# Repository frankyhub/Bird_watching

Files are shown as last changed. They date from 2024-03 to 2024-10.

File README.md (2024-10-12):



<div align="center">

|[:skull:ISSUE](https://github.com/frankyhub/Bird_watching/issues?q=is%3Aissue)|[:speech_balloon: Forum /Discussion](https://github.com/frankyhub/Bird_watching/discussions)|[:grey_question:WiKi](https://github.com/frankyhub/Bird_watching/wiki)||
|--|--|--|--|
| | | | |
||<a href="https://github.com/frankyhub/Bird_watching/issues">|<a href="https://github.com/frankyhub/Bird_watching/discussions">|<a href="https://github.com/frankyhub/Bird_watching/releases">|
|| <a href="https://github.com/frankyhub/Bird_watching/pulse" alt="Activity">| <a href="https://github.com/frankyhub/Bird_watching/graphs/traffic">  |<a href="https://github.com/frankyhub?tab=stars"> |
</div>

# Bird watching 
### Nach einer Idee von [Alex Kutschera](https://github.com/vektorious)

### Story
Die Blaumeise und die Kohlmeise gehören zu den häufigsten Meisenarten in Deutschland. Sie gehen nicht nur gerne an Futterhäuschen, sondern suchen auch Nistkästen auf, in denen sie Schutz suchen und ihre Familie gründen können. Für jede Vogelart gibt es eine ideale Größe des Einfluglochs. Bei den kleinen Blaumeisen sind das 28 Millimeter Durchmesser, bei den größeren Kohlmeisen 32 und beim Star 45mm Lochgröße. Die Lightburnvorlage ist für Kohlmeisen ausgelegt.  Das Einflugloch sollte in Richtung Ost / Südost ausgerichtet sein. 

Die Kohlmeise ist ein kleiner Singvogel. Sie hat einen schwarzen Kopf, weiße Wangen und gelbes Gefieder an Brust und Bauch, sie sind etwa 11 bis 12 Zentimeter groß und wiegen zwischen 9 und 12 Gramm. Mit der CAM des ESP32 und dem WEB-Server kann man in den Nistkasten das Schlüpfen der Jungvögel beobachten. Die 4 IR-LEDs lassen sich über den WEB-Server ein/aus schalten. Der WEB-Server hat eine feste IP-Adresse: 192.160.0.177. Um den WiFi-Empfang des ESP zu verbessern, wurde die Antenne des ESP32-CAM mit 40cm Litze verlängert. In der Testphase ist mit dem Serielllen Monitor die WiFi-Verbindung und die Schaltvorgänge der IR-LEDs zu kontrollieren. Für die Spannungsversorgung ist ein 5V-Netzteil vorgesehen. Möglich ist auch eine Spannungsversorgung mit einem 18650 Akku, der von einem Solor-Panel gespeist wird.

---

### Der WEB-Server:

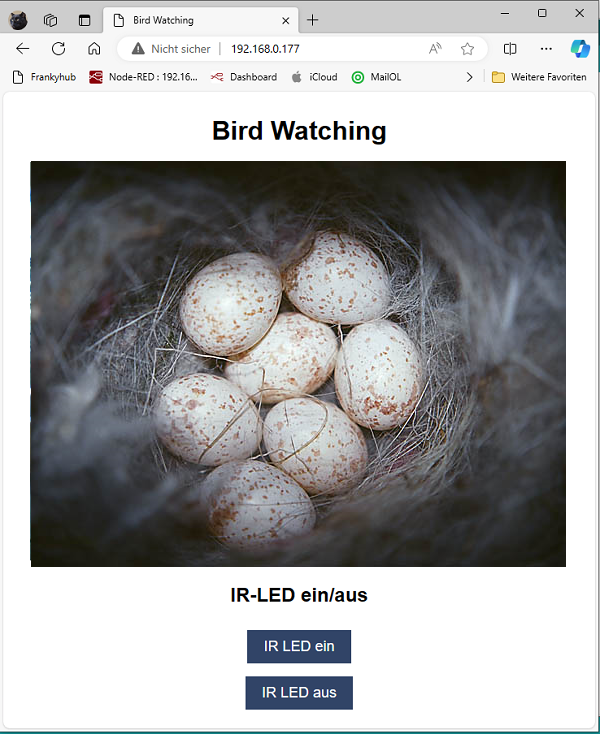
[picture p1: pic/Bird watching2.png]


---

### Serieller Monitor:

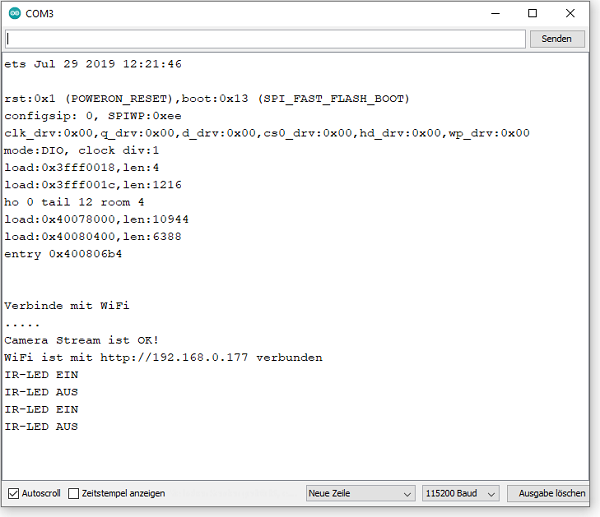
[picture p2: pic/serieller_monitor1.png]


---

### BOM

| Stück | Bezeichnung |
| ----- | --- |
| 1 | ESP32 CAM | 
| 1 | ESP32 CAM Shield | 
| 4 | IR-LEDs 850 nm DC 1,5V 20mA | 
| 4 | 75R 1/4W  | 
| 1 | 10cm Blankdraht  | 
| 1 | 40cm Litze für die Wurfantenne  | 
| 1 | Schaltdraht |
| 1 | 5V Netzteil |
| 1 | Vogelhaus: |
| 2 | Sperrholz 4mm 300x600 |
| ----- | ----------- | 

---

[Bauanleitung](https://github.com/frankyhub/Bird_watching/wiki)

---

### Birdhouse aus dem Lasercutter:

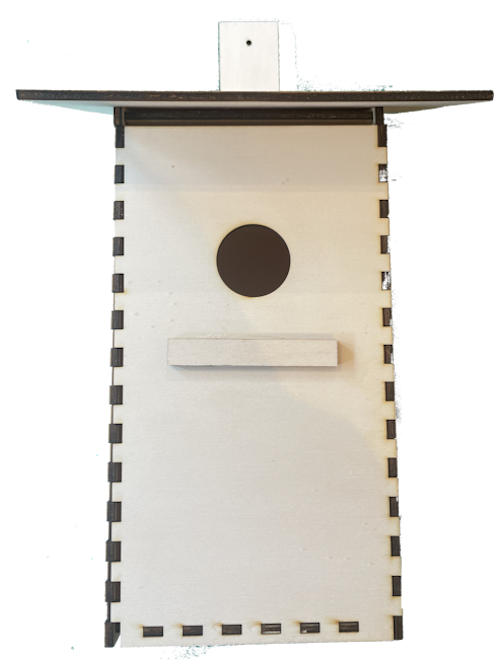
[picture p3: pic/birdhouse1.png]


### CAM-Bild

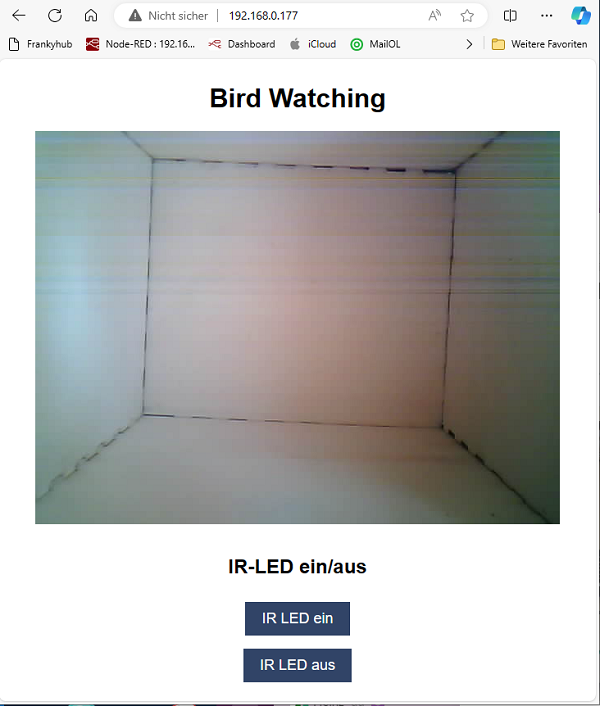
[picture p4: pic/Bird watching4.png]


### Verdrahtung des ESP32-CAM und der IR-LEDs

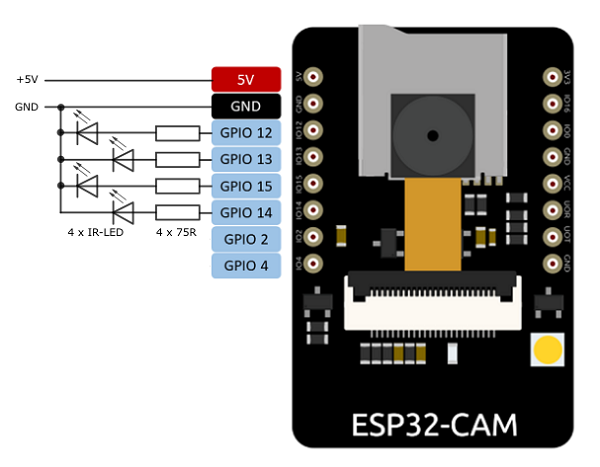
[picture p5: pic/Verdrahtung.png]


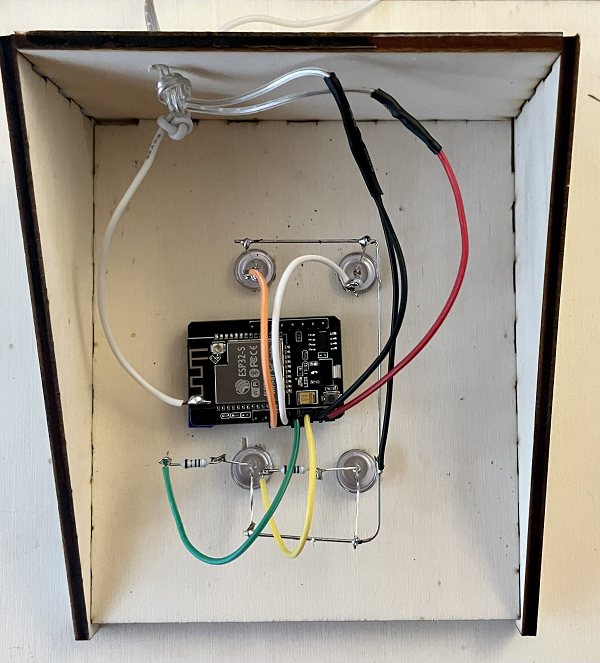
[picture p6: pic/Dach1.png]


---

<div style="position:absolute; left:2cm; ">   
<ol class="breadcrumb" style="border-top: 2px solid black;border-bottom:2px solid black; height: 45px; width: 900px;"> <p align="center"><a href="#oben">nach oben</a></p></ol>
</div>

---

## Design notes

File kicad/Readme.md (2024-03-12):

## ESP32-CAM Shield

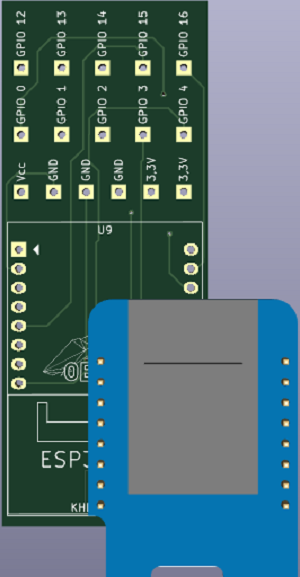
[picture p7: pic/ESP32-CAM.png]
Bild


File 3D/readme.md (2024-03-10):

## ESP32-CAM Spacer

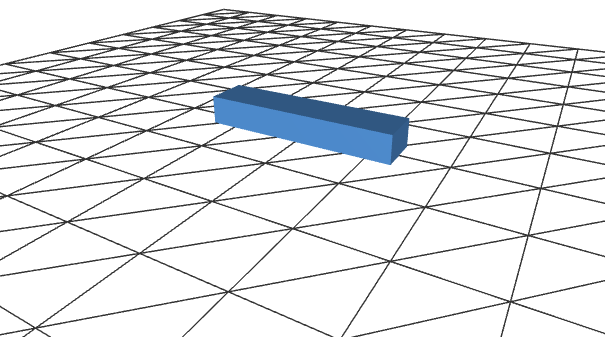
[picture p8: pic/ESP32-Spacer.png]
STL


## Box 1
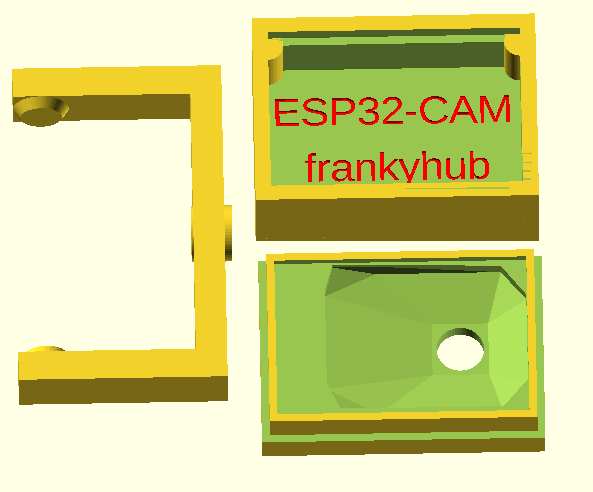
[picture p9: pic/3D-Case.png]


## Box 2
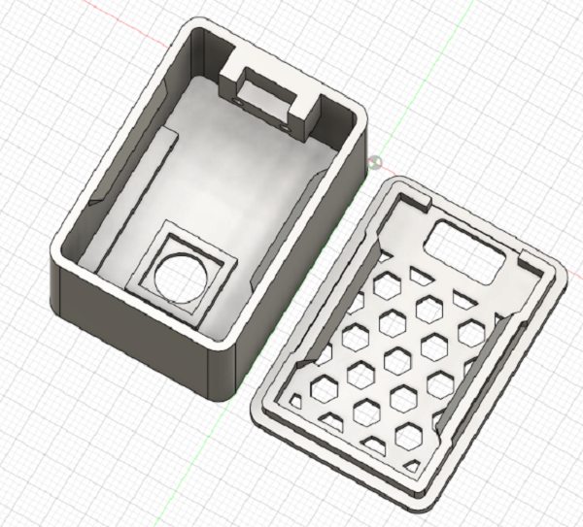
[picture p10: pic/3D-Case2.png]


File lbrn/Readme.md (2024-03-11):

## Lightburn Dach

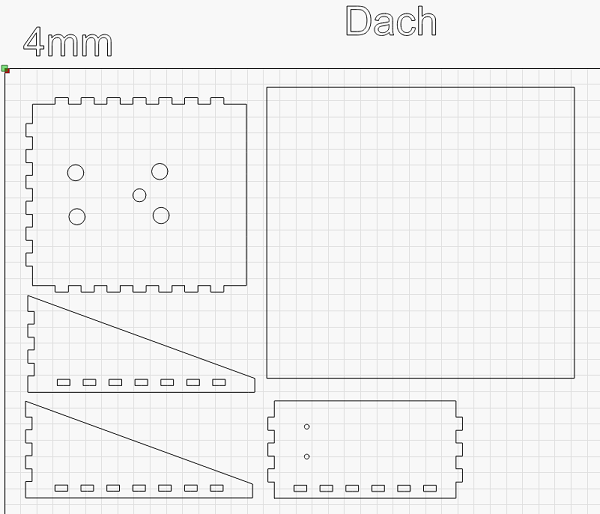
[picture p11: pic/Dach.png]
Bild


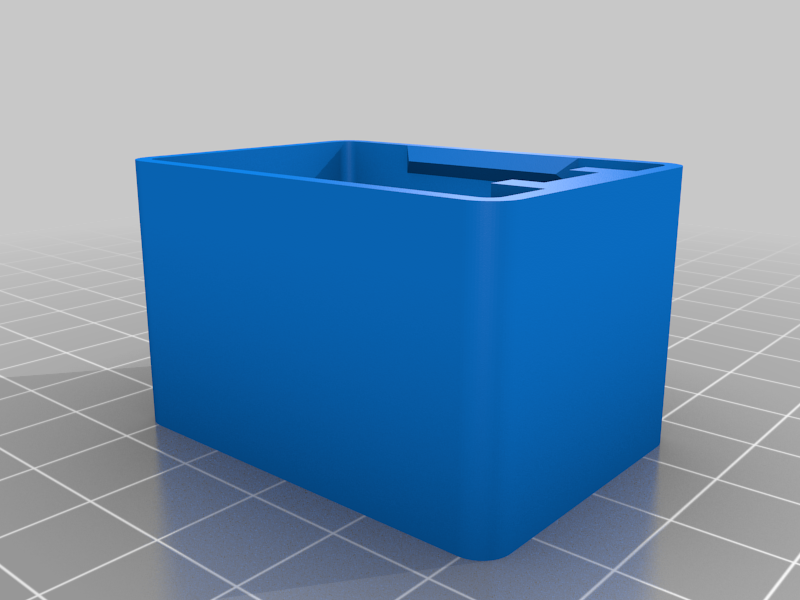
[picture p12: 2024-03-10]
pic/ESP32-CAM-Box2.png

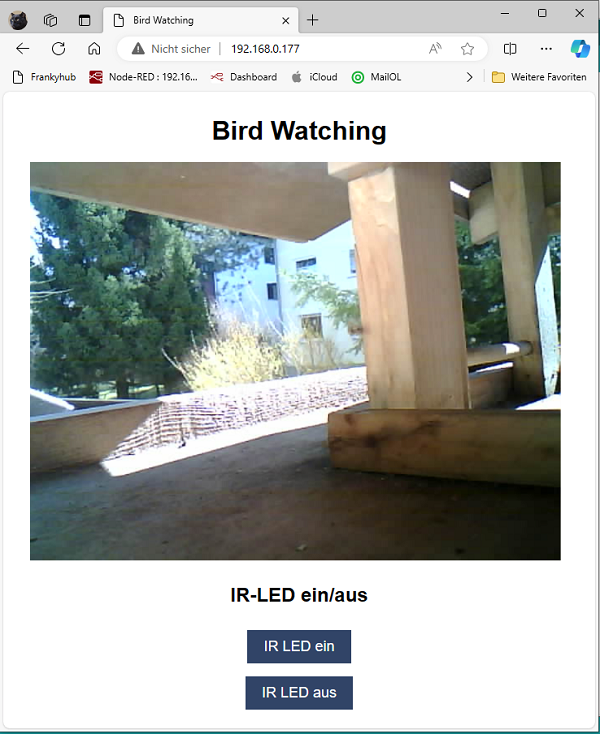
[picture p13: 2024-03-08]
pic/Bird watching1.png

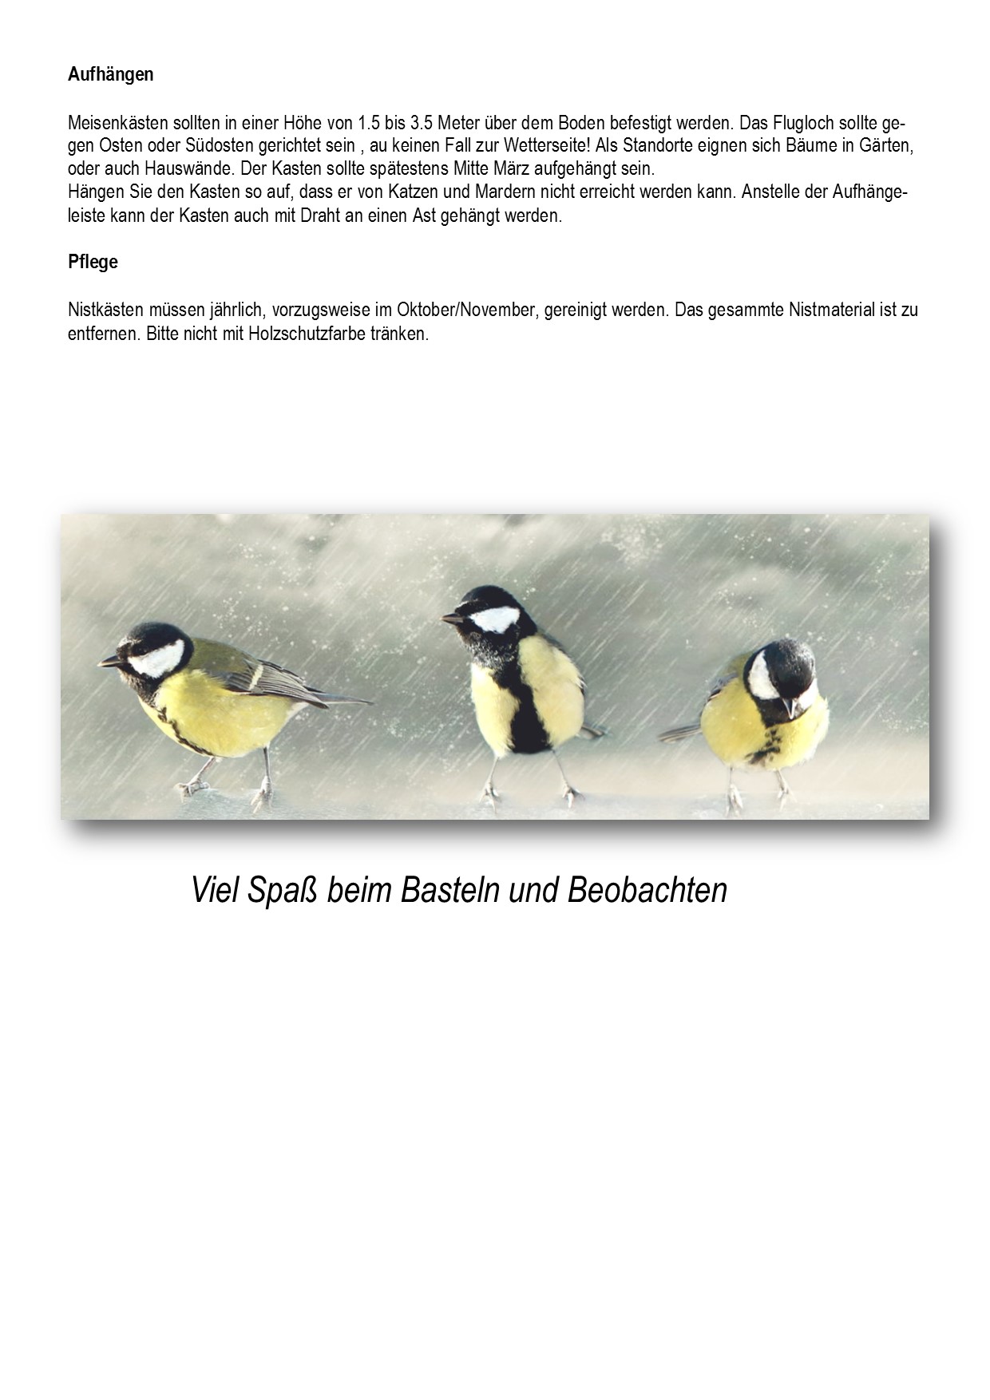
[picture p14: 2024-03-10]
pic/meisenkasten 3.jpg

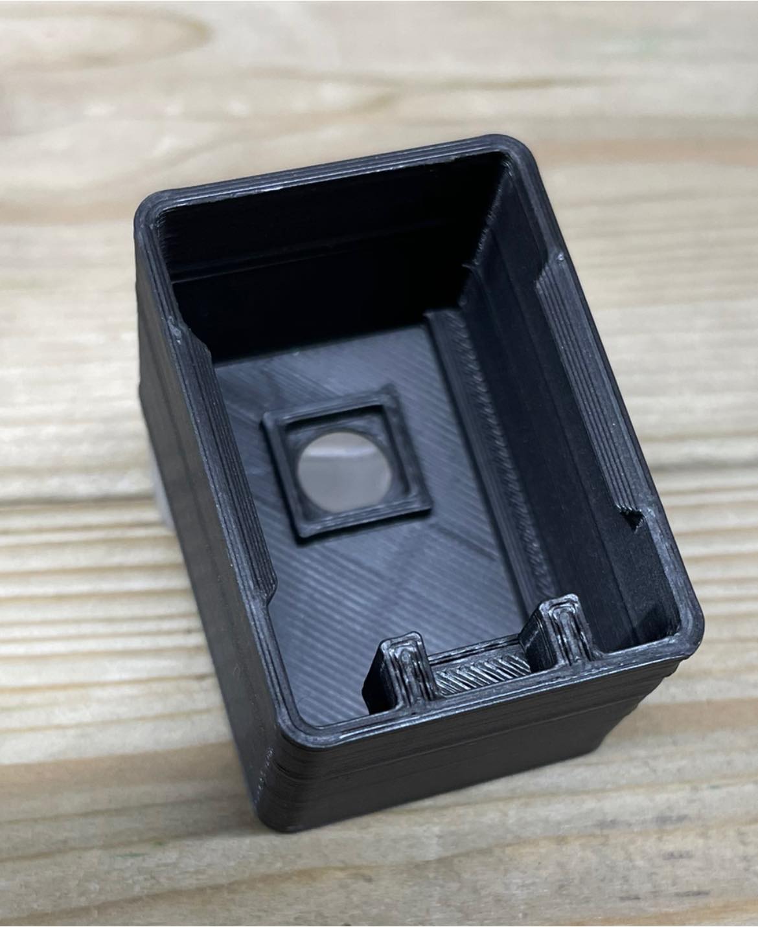
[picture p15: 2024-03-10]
pic/Rear_box2.jpg

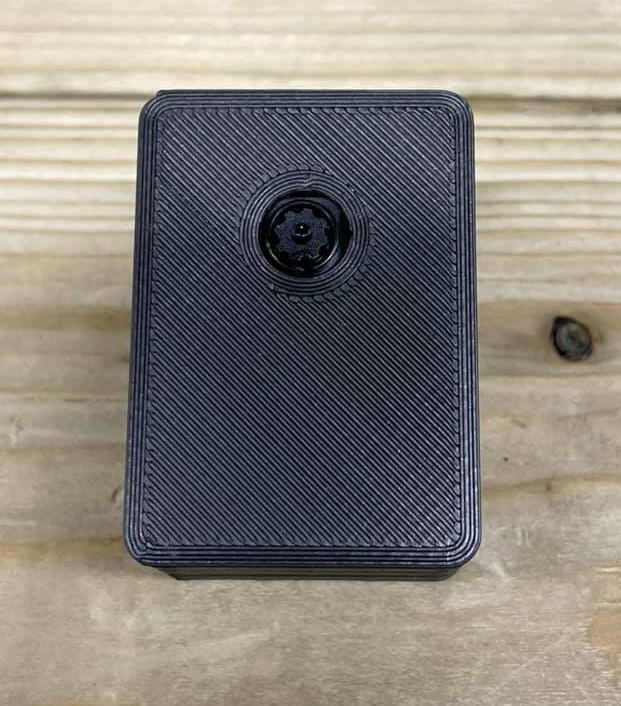
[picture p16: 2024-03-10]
pic/Front_box2.jpg

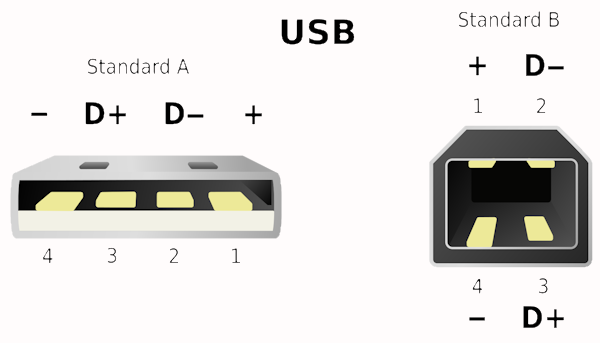
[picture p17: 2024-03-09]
pic/usb.png

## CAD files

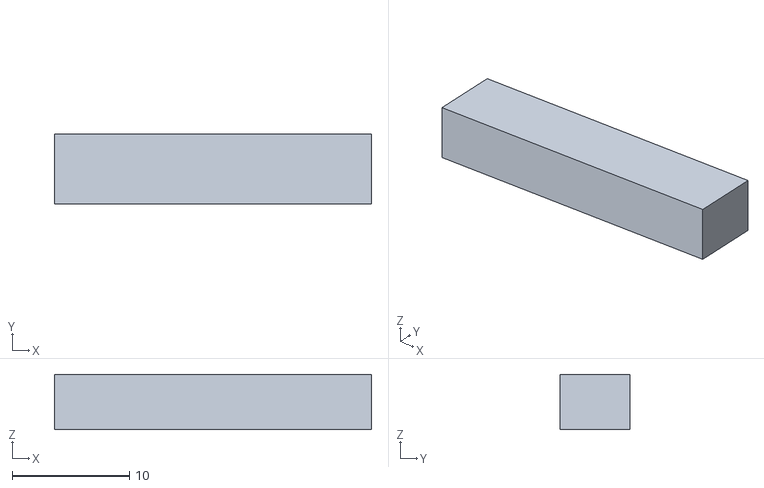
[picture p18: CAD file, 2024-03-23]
3D/ESP Spacer.stl
27.0 x 6.00 x 4.70

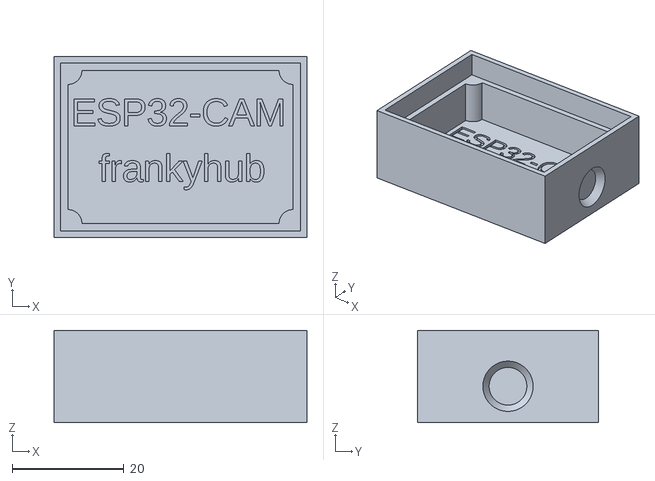
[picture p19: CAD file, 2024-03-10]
3D/esp32cam-box-bottom.stl
45.3 x 32.4 x 16.5

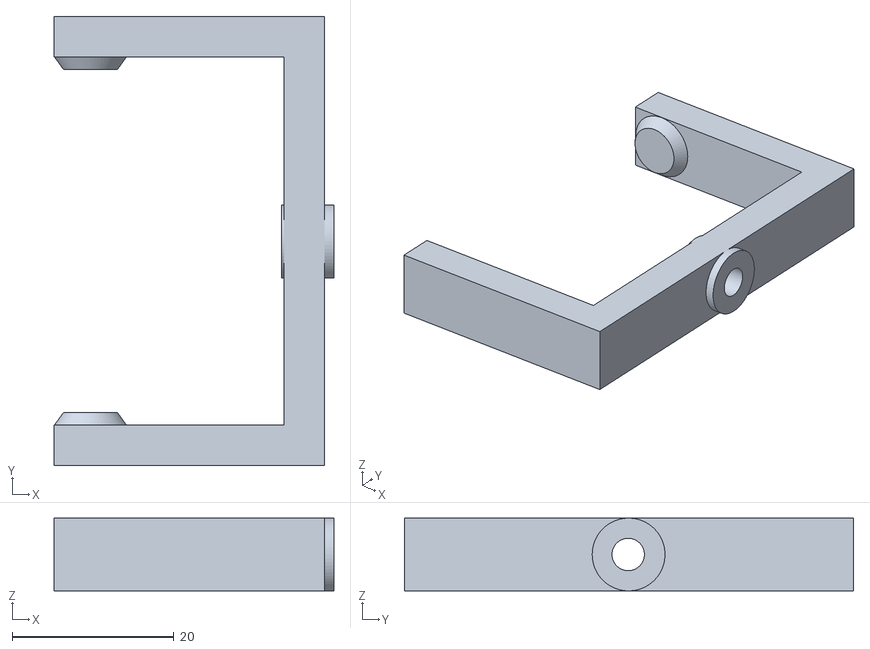
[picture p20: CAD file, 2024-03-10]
3D/esp32cam-box-bracket.stl
34.6 x 55.5 x 9.00

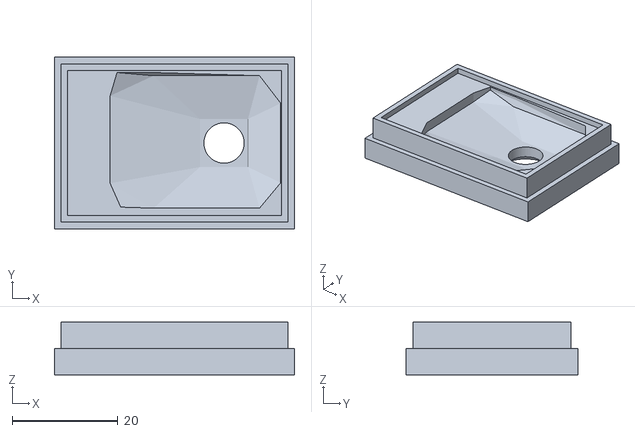
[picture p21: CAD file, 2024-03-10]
3D/esp32cam-box-top.stl
45.3 x 32.4 x 10.0

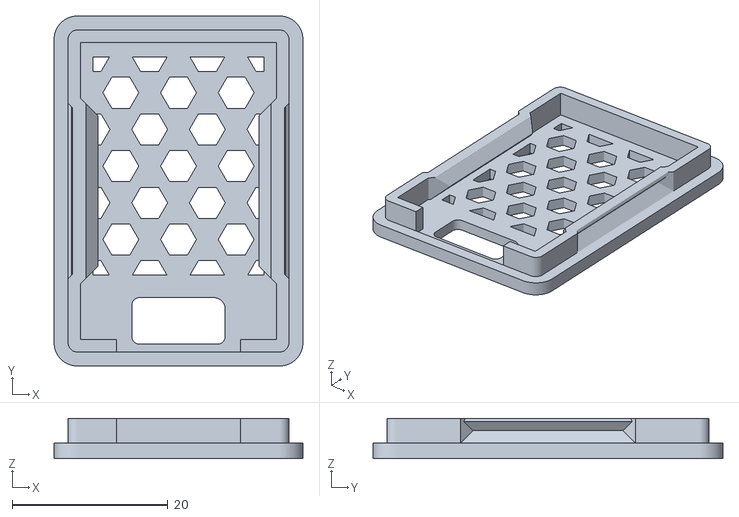
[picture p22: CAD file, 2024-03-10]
3D/ESP32-CAM-Lid2.stl
32.0 x 45.0 x 5.20

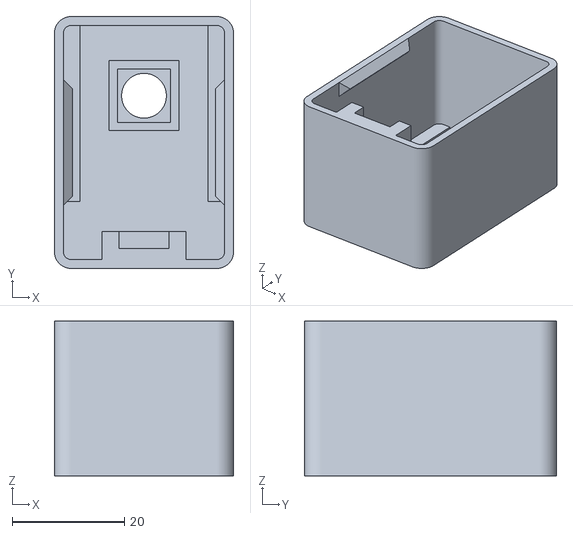
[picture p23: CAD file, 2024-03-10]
3D/ESP32-CAM-Box2.stl
32.0 x 45.0 x 27.6

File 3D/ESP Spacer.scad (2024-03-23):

//ESP Spacer

$fn=60;

cube(size = [27,6,4.7], center = true);

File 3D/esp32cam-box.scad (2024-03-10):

/*
*******************************************
Objekt Info: ESP32-CAM mit Modul-Auswahl

*******************************************
Version: 10.03.2024 khf
*******************************************
*/

//***************   Auswahl   *************

//Auswahl 0=alles, 1= bottom, 2=top, 3=bracket 
        auswahl="0";

//***************   Libraries  ************

//keine

//*****************************************

//***************  Parameter   *************
$fn=60;
//*****************************************

//**************   Programm  **************


pcbx = 40.1+0.2;  // pcb long dimension
pcby = 27.2+0.2;  // pcb shorter dimension
pcbz = 1.05+0.2;  // pcb thickness

lensd = 7.1+0.5;  // lens dia
lensx = 29.5;
lensy = pcby /2.0;
lensz = 5.4;  // bottom of pcb to base of lens
lensh = 2.25+0.2; // height of lens + extra
cambx = 8.65+0.4; // clearance needed for body of camera
camby = 8.65+0.4;

boxwall = 5.0;    // wall thickness
toph   = 10.0;    // thickness of top box

pinh = 9.0;   // how much space needed for pins on rear of pcb

// generate a shape model of the camera upper surface and pcb
// this gets subtracted from a solid base to form a pocket that
// holds the pcb and camera in place.

module camera()
{
  hull()
  {
    translate([lensx-cambx/2,lensy-camby/2,0]) cube([cambx,camby,lensz]);   // camera body
    translate([16.2,1,0]) cube([20,2,3.5]);                                 // room for pins
    translate([16.2,24.0,0]) cube([20,2,3.5]);                              // room for pins
    translate([25.2,pcby/2-7.5,0]) cube([15.0,15.0,3.0]);                   // sdcard slot
    translate([9.3,0.4,0]) cube([7,3.5,2.0]);                               // led + xsistor
    translate([8,4.8,0]) cube([9.4,16.5,3.5]);                              // cam connector
    translate([17.3,3.5,0]) cube([7.75,19.75,3.1]);                         // cable + parts
    translate([10.0,22.3,0]) cube([6.5,3.5,2.2]);                           // reg + parts
  }
  cube([pcbx,pcby,pcbz]);
  //translate([1,pcby-4,pcbz]) rotate([0,0,-90]) linear_extrude(0.5) text("ESP32-CAM",2.5);
  translate([lensx,lensy,lensz]) cylinder(h=lensh, d=lensd);  // lens
  translate([lensx,lensy,lensz+lensh]) cylinder(h=6, d1=lensd, d2=3*lensd); // lens flare
  // below is optional... only needed if you need to put an sd card in the camera
  //translate([40.0,pcby/2-7.5,pcbz]) cube([15.0,15.0,3.0-pcbz]);             // sdcard slot access
}

module boxjoint()
{
  difference()
  {
    cube([pcbx+boxwall,pcby+boxwall,toph/2]);    
    translate([boxwall/4,boxwall/4,0]) cube([pcbx+boxwall/2,pcby+boxwall/2,toph]);
  }
}
module bracket()
{
  hole=4.0;   // mounting hole size
  clrn = 0.1; // clearance for pivot
  difference() 
  {
    union()
    {
      cube([pcbx+boxwall+clrn*2,boxwall,pinh]);
      translate([-boxwall,0,0]) cube([boxwall,pcby+6,pinh]);
      translate([pcbx+boxwall+clrn*2,0,0]) cube([boxwall,pcby+6,pinh]);
      // 2 pins to engage box
      translate([0,pcby-pinh/2+6,pinh/2]) rotate([0,90,0])             cylinder(h=boxwall/3-clrn,d1=pinh-clrn,d2=pinh*0.75-clrn);
      translate([pcbx+boxwall+clrn*2,pcby-pinh/2+6,pinh/2]) rotate([0,-90,0]) cylinder(h=boxwall/3-clrn,d1=pinh-clrn,d2=pinh*0.75-clrn);
      // a reinforcing boss on mounting screw
      translate([(pcbx+boxwall+clrn)/2,-1.2,pinh/2]) rotate([-90,0,0])cylinder(d=pinh,h=boxwall*1.3);

    }
    // cutout mounting hole for #6 screw
    translate([(pcbx+boxwall)/2,-boxwall*5,pinh/2]) rotate([-90,0,0])cylinder(d=hole,h=boxwall*10);
  } 
}

module top()
{
  difference()
  {
    cube([pcbx+boxwall,pcby+boxwall,toph]);
    union()
    {
      translate([boxwall/2,boxwall/2,0]) camera();  // carve out camera
      boxjoint();                                   // carve off the box overlap
    }
  }
}

module bottom()
{
  both = pinh + boxwall/2 + toph/2; // total ht of bottom box
  clr = 0.1;    // a little fudge to make boxes mate
  difference()
  {
    cube([pcbx+boxwall,pcby+boxwall,both]);
    union()
    {
      // cutout for pcb connections
      translate([boxwall/2,boxwall/2,boxwall/2]) cube([pcbx,pcby,both]);
      // cutout for overlap
      translate([boxwall/4-clr/2,boxwall/4-clr/2,both-toph/2]) cube([pcbx+boxwall/2+clr,pcby+boxwall/2+clr,toph/2]);
      //tapered plug cutouts for mounting bracket
      translate([0,(pcby+boxwall)/2,pinh/2+2]) rotate([0,90,0])             cylinder(h=boxwall/3,d1=pinh,d2=pinh*0.75);
      translate([pcbx+boxwall,(pcby+boxwall)/2,pinh/2+2]) rotate([0,-90,0]) cylinder(h=boxwall/3,d1=pinh,d2=pinh*0.75);
      // sign work by embossing inside of bottom of box (adds compute time, but saves some filament!
        
 color( "red", 1.0 ) {        
      translate([3,20,boxwall/2-0.5]) rotate([0,0,0]) linear_extrude(0.55) text("ESP32-CAM",5);
      translate([8,10,boxwall/2-0.5]) rotate([0,0,0]) linear_extrude(0.55) text("frankyhub",5);
      }    
    }
  }
  // add some posts in the corners to hold pcb in top of case when mated
  translate([boxwall/2,boxwall/2,boxwall/2]) cylinder(h=pinh,d=boxwall);
  translate([boxwall/2,boxwall/2+pcby,boxwall/2]) cylinder(h=pinh,d=boxwall);
  translate([boxwall/2+pcbx,boxwall/2,boxwall/2]) cylinder(h=pinh,d=boxwall);
  translate([boxwall/2+pcbx,boxwall/2+pcby,boxwall/2]) cylinder(h=pinh,d=boxwall);
}

module alles(){
    bottom();
    translate([0,-5,toph]) rotate([180,0,0])  top();
    translate([-boxwall,-(pcbx+boxwall)/2,0]) rotate([0,0,90]) bracket();
}


//-----------------------------------------------------------------

module print(){
	if (auswahl == "1") {
		bottom();
	} else if (auswahl == "2") {
		translate([0,-5,toph]) rotate([180,0,0])  
        top();
	} else if (auswahl == "3") {
		// flip top over and move it for printing
        translate([-boxwall,-(pcbx+boxwall)/2,0]) rotate([0,0,90]) 
        bracket();
	} else {
		alles();
	}
}

print();
//-----------------------------------------------------------------

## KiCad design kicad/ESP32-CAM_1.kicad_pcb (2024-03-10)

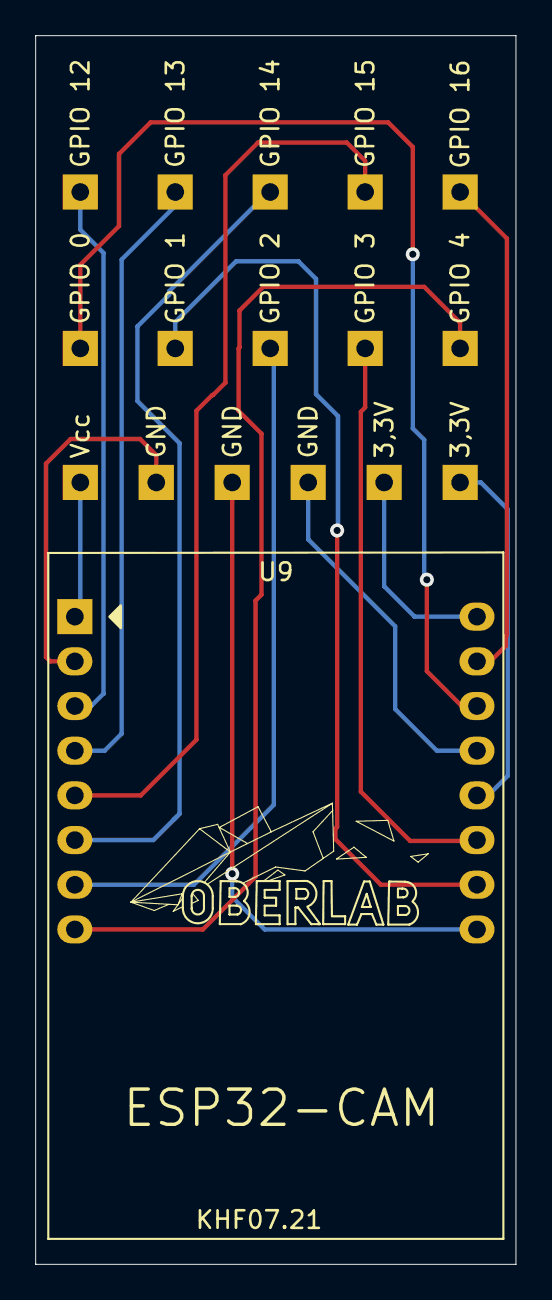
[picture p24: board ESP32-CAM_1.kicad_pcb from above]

Board: 2 copper layers, 27.3 x 69.8 mm, 17 parts (0 on the bottom side), 16 nets.

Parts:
3,3V, 3,3V#2: LP
GND: LP
GND#2, GND#3: LP
GPIO 0, GPIO 1, GPIO 2, GPIO 3, GPIO 4, GPIO 12, GPIO 13, GPIO 14, GPIO 15, GPIO 16: LP
U9: ESP32-CAM
Vcc: LP

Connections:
unnamed: U9.1, Vcc.1
unnamed: GND.1, U9.2
unnamed: GPIO 12.1, U9.3
unnamed: GPIO 13.1, U9.4
unnamed: GPIO 15.1, U9.5
unnamed: GPIO 14.1, U9.6
unnamed: GPIO 2.1, U9.7
unnamed: GPIO 4.1, U9.8
unnamed: 3,3V.1, U9.16
unnamed: GPIO 16.1, U9.15
unnamed: GPIO 0.1, U9.14
unnamed: GND#2.1, U9.13
unnamed: 3,3V#2.1, U9.12
unnamed: GPIO 3.1, U9.11
unnamed: GPIO 1.1, U9.10
unnamed: GND#3.1, U9.9

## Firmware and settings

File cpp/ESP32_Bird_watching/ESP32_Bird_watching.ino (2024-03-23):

/*************************************************************************************************
                                      PROGRAMMINFO
**************************************************************************************************
  Funktion: ESP32-CAM Bird Watching, WEB-Server

  IR-LED on/off
  static IP (192, 168, 0, 177)
**************************************************************************************************
  Version: 07.03.2024
**************************************************************************************************
  Board:  ESP32 Wrover Module
**************************************************************************************************
  C++ Arduino IDE V1.8.13
**************************************************************************************************
  Einstellungen:
  https://dl.espressif.com/dl/package_esp32_index.json
  http://dan.drown.org/stm32duino/package_STM32duino_index.json
  https://raw.githubusercontent.com/espressif/arduino-esp32/gh-pages/package_esp32_dev_index.json
**************************************************************************************************
  Librarys
  - WiFi.h V0.16.1
**************************************************************************************************


**************************************************************************************************/

#include "esp_camera.h"
#include <WiFi.h>
#include "esp_timer.h"
#include "img_converters.h"
#include "Arduino.h"
#include "fb_gfx.h"
#include "esp_http_server.h"


// ***** Trage hier deine WLAN Daten ein *********************************
const char* ssid = "ESP32";
const char* password = "xxx";
//************************************************************************

// ***** Statische IP-Adresse ********************************************
IPAddress local_IP(192, 168, 0, 177);
// Gateway IP Addresse
IPAddress gateway(192, 168, 0, 1);

IPAddress subnet(255, 255, 0, 0);
IPAddress primaryDNS(8, 8, 8, 8);   //optional
IPAddress secondaryDNS(8, 8, 4, 4); //optional

//************************************************************************


#define PART_BOUNDARY "123456789000000000000987654321"

//CAMERA_MODEL_AI_THINKER
#define PWDN_GPIO_NUM     32
#define RESET_GPIO_NUM    -1
#define XCLK_GPIO_NUM      0
#define SIOD_GPIO_NUM     26
#define SIOC_GPIO_NUM     27
#define Y9_GPIO_NUM       35
#define Y8_GPIO_NUM       34
#define Y7_GPIO_NUM       39
#define Y6_GPIO_NUM       36
#define Y5_GPIO_NUM       21
#define Y4_GPIO_NUM       19
#define Y3_GPIO_NUM       18
#define Y2_GPIO_NUM        5
#define VSYNC_GPIO_NUM    25
#define HREF_GPIO_NUM     23
#define PCLK_GPIO_NUM     22


//******* IR-LED *********************************************************
int LED_1 = 12;
int LED_2 = 13;
int LED_3 = 14;
int LED_4 = 15;
//************************************************************************

static const char* _STREAM_CONTENT_TYPE = "multipart/x-mixed-replace;boundary=" PART_BOUNDARY;
static const char* _STREAM_BOUNDARY = "\r\n--" PART_BOUNDARY "\r\n";
static const char* _STREAM_PART = "Content-Type: image/jpeg\r\nContent-Length: %u\r\n\r\n";

//********************WEB-Server ****************************************************
httpd_handle_t camera_httpd = NULL;
httpd_handle_t stream_httpd = NULL;

static const char PROGMEM INDEX_HTML[] = R"rawliteral(
<html>
  <head>
    <title>Bird Watching</title>
    <meta name="viewport" content="width=device-width, initial-scale=1">
    <style>
      body { font-family: Arial; text-align: center; margin:0px auto; padding-top: 30px;}
      table { margin-left: auto; margin-right: auto; }
      td { padding: 8 px; }
      .button {
        background-color: #2f4468;
        border: none;
        color: white;
        padding: 10px 20px;
        text-align: center;
        text-decoration: none;
        display: inline-block;
        font-size: 18px;
        margin: 6px 3px;
        cursor: pointer;
        -webkit-touch-callout: none;
        -webkit-user-select: none;
        -khtml-user-select: none;
        -moz-user-select: none;
        -ms-user-select: none;
        user-select: none;
        -webkit-tap-highlight-color: rgba(0,0,0,0);
      }
      img {  width: auto ;
        max-width: 100% ;
        height: auto ; 
      }
    </style>
  </head>
  <body>
    <h1>Bird Watching</h1>
    <img src="" id="photo" >
    <br>
    <br>
    <h2> IR-LED ein/aus      </h2>

    <table>
      <tr><td colspan="3" align="center"><button class="button" onmousedown="toggleCheckbox('LED_ein');" ontouchstart="toggleCheckbox('LED_ein');">IR LED ein</button></td></tr>
      <tr><td             align="center"><button class="button" onmousedown="toggleCheckbox('LED_aus');" ontouchstart="toggleCheckbox('LED_aus');">IR LED aus</button></td></tr> 
     
   <script>
   function toggleCheckbox(x) {
     var xhr = new XMLHttpRequest();
     xhr.open("GET", "/action?go=" + x, true);
     xhr.send();
   }
   window.onload = document.getElementById("photo").src = window.location.href.slice(0, -1) + ":81/stream";
  </script>
  </body>
</html>
)rawliteral";

//************************************************************************

static esp_err_t index_handler(httpd_req_t *req){
  httpd_resp_set_type(req, "text/html");
  return httpd_resp_send(req, (const char *)INDEX_HTML, strlen(INDEX_HTML));
}

static esp_err_t stream_handler(httpd_req_t *req){
  camera_fb_t * fb = NULL;
  esp_err_t res = ESP_OK;
  size_t _jpg_buf_len = 0;
  uint8_t * _jpg_buf = NULL;
  char * part_buf[64];

  res = httpd_resp_set_type(req, _STREAM_CONTENT_TYPE);
  if(res != ESP_OK){
    return res;
  }

  while(true){
    fb = esp_camera_fb_get();
    if (!fb) {
      Serial.println("Camera capture failed");
      res = ESP_FAIL;
    } else {
      if(fb->width > 400){
        if(fb->format != PIXFORMAT_JPEG){
          bool jpeg_converted = frame2jpg(fb, 80, &_jpg_buf, &_jpg_buf_len);
          esp_camera_fb_return(fb);
          fb = NULL;
          if(!jpeg_converted){
            Serial.println("JPEG compression failed");
            res = ESP_FAIL;
          }
        } else {
          _jpg_buf_len = fb->len;
          _jpg_buf = fb->buf;
        }
      }
    }
    if(res == ESP_OK){
      size_t hlen = snprintf((char *)part_buf, 64, _STREAM_PART, _jpg_buf_len);
      res = httpd_resp_send_chunk(req, (const char *)part_buf, hlen);
    }
    if(res == ESP_OK){
      res = httpd_resp_send_chunk(req, (const char *)_jpg_buf, _jpg_buf_len);
    }
    if(res == ESP_OK){
      res = httpd_resp_send_chunk(req, _STREAM_BOUNDARY, strlen(_STREAM_BOUNDARY));
    }
    if(fb){
      esp_camera_fb_return(fb);
      fb = NULL;
      _jpg_buf = NULL;
    } else if(_jpg_buf){
      free(_jpg_buf);
      _jpg_buf = NULL;
    }
    if(res != ESP_OK){
      break;
    }
   }
  return res;
}

static esp_err_t cmd_handler(httpd_req_t *req){
  char*  buf;
  size_t buf_len;
  char variable[32] = {0,};
  
  buf_len = httpd_req_get_url_query_len(req) + 1;
  if (buf_len > 1) {
    buf = (char*)malloc(buf_len);
    if(!buf){
      httpd_resp_send_500(req);
      return ESP_FAIL;
    }
    if (httpd_req_get_url_query_str(req, buf, buf_len) == ESP_OK) {
      if (httpd_query_key_value(buf, "go", variable, sizeof(variable)) == ESP_OK) {
      } else {
        free(buf);
        httpd_resp_send_404(req);
        return ESP_FAIL;
      }
    } else {
      free(buf);
      httpd_resp_send_404(req);
      return ESP_FAIL;
    }
    free(buf);
  } else {
    httpd_resp_send_404(req);
    return ESP_FAIL;
  }

  sensor_t * s = esp_camera_sensor_get();
  int res = 0;
  
//************ IR-LED e/a **********************************************  

  if(!strcmp(variable, "LED_ein")) {
    Serial.println("IR-LED EIN");
    digitalWrite(LED_1, 1);
        digitalWrite(LED_2, 1);
            digitalWrite(LED_3, 1);
                digitalWrite(LED_4, 1);
  }

  else if(!strcmp(variable, "LED_aus")) {
    Serial.println("IR-LED AUS");
    digitalWrite(LED_1, 0);
        digitalWrite(LED_2, 0);
            digitalWrite(LED_3, 0);
                digitalWrite(LED_4, 0);
  }
  
  else {
    res = -1;
  }

//**********************************************************************

  if(res){
    return httpd_resp_send_500(req);
  }

  httpd_resp_set_hdr(req, "Access-Control-Allow-Origin", "*");
  return httpd_resp_send(req, NULL, 0);
}

//**************** Camera Server **************************************
void startCameraServer(){
  httpd_config_t config = HTTPD_DEFAULT_CONFIG();
  config.server_port = 80;
  httpd_uri_t index_uri = {
    .uri       = "/",
    .method    = HTTP_GET,
    .handler   = index_handler,
    .user_ctx  = NULL
  };

  httpd_uri_t cmd_uri = {
    .uri       = "/action",
    .method    = HTTP_GET,
    .handler   = cmd_handler,
    .user_ctx  = NULL
  };
  httpd_uri_t stream_uri = {
    .uri       = "/stream",
    .method    = HTTP_GET,
    .handler   = stream_handler,
    .user_ctx  = NULL
  };
  if (httpd_start(&camera_httpd, &config) == ESP_OK) {
    httpd_register_uri_handler(camera_httpd, &index_uri);
    httpd_register_uri_handler(camera_httpd, &cmd_uri);
  }
  config.server_port += 1;
  config.ctrl_port += 1;
  if (httpd_start(&stream_httpd, &config) == ESP_OK) {
    httpd_register_uri_handler(stream_httpd, &stream_uri);
  }
}
//**********************************************************************

//**************** setup ***********************************************
void setup() {

  pinMode (LED_1, OUTPUT);
  pinMode (LED_2, OUTPUT);
  pinMode (LED_3, OUTPUT);
  pinMode (LED_4, OUTPUT);

  Serial.begin(115200);
  Serial.setDebugOutput(false);
  
  camera_config_t config;
  config.ledc_channel = LEDC_CHANNEL_0;
  config.ledc_timer = LEDC_TIMER_0;
  config.pin_d0 = Y2_GPIO_NUM;
  config.pin_d1 = Y3_GPIO_NUM;
  config.pin_d2 = Y4_GPIO_NUM;
  config.pin_d3 = Y5_GPIO_NUM;
  config.pin_d4 = Y6_GPIO_NUM;
  config.pin_d5 = Y7_GPIO_NUM;
  config.pin_d6 = Y8_GPIO_NUM;
  config.pin_d7 = Y9_GPIO_NUM;
  config.pin_xclk = XCLK_GPIO_NUM;
  config.pin_pclk = PCLK_GPIO_NUM;
  config.pin_vsync = VSYNC_GPIO_NUM;
  config.pin_href = HREF_GPIO_NUM;
  config.pin_sscb_sda = SIOD_GPIO_NUM;
  config.pin_sscb_scl = SIOC_GPIO_NUM;
  config.pin_pwdn = PWDN_GPIO_NUM;
  config.pin_reset = RESET_GPIO_NUM;
  config.xclk_freq_hz = 20000000;
  config.pixel_format = PIXFORMAT_JPEG; 
  
  if(psramFound()){
    config.frame_size = FRAMESIZE_VGA;
    config.jpeg_quality = 10;
    config.fb_count = 2;
  } else {
    config.frame_size = FRAMESIZE_SVGA;
    config.jpeg_quality = 12;
    config.fb_count = 1;
  }
  
  // Camera init
  esp_err_t err = esp_camera_init(&config);
  if (err != ESP_OK) {
    Serial.printf("Camera init failed with error 0x%x", err);
    return;
  }

//+++++++++++++++++ WIFI statische IP Adresse +++++++++++++++++++++++++++++++++++++++++++++++

  if (!WiFi.config(local_IP, gateway, subnet, primaryDNS, secondaryDNS)) {
    Serial.println("STA Failed to configure");
  }
  WiFi.begin(ssid, password);
  WiFi.setSleep(false);

  Serial.println("");
  Serial.println("Verbinde mit WiFi ");
    
  while (WiFi.status() != WL_CONNECTED) {
    delay(500);
    Serial.print(".");
  }
  Serial.println("");
  Serial.println("Camera Stream ist OK!");
  Serial.println("WiFi ist mit http://192.168.0.177 verbunden");

//+++++++++++++++++++++++++++++++++++++++++++++++++++++++++++++++++++

  
  // Start web server
  startCameraServer();
}

void loop() {
  
}

//************************** END **********************************************

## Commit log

2024-03-10 V1.0 10.03.2024
    [ESP32-CAM_1.kicad_pcb, ESP32-CAM_1.sch]
2024-03-10 IR-LED Update README.md
2024-03-10 V1.1 10.03.2024 IR-LED
2024-03-10 V1.3 8mm Cam 10.03.2024
2024-03-10 V1,0 ESP-Spacer 10.03.2024
2024-03-10 V1 10.03.2024
    [ESP32-CAM-Box2.stl, ESP32-CAM-Lid2.stl, esp32cam-box.scad]
2024-03-10 V1,1 10.03.2024
    [esp32cam-box.scad]
2024-03-23 V1.4 23.03.2024 IR-LED, Antenne
    [ESP Spacer.stl]
2024-03-23 V1.4 23.04.2024 IR-LED, Antenne
2024-03-23 V1.1 24.03.2024
    [ESP Spacer.scad]
2024-03-23 V1.2 23.03.2024 IR-LED
2024-03-24 V1.5 24.03.2024 IR-LED, 5V, Antenne
2024-03-24 V1.5 24.03.2024 IR-LED, 5V, Antenne
